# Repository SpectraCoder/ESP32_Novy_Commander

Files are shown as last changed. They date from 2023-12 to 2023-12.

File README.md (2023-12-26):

# ESP32 Novy Commander

The main goal of this project is to control the lights of the Novy Crystal 26050 cooking hood when the Zigbee kitchen lights are turned on or off.
The ESP32 looks at the API of Home Assistant to determine the on or off state of the kitchen lights, and sends a 433mhz signal to the connected 433mhz transmitter.
The ip address of the ESP32 shows a basic status web page with the ability to reboot the device.
 
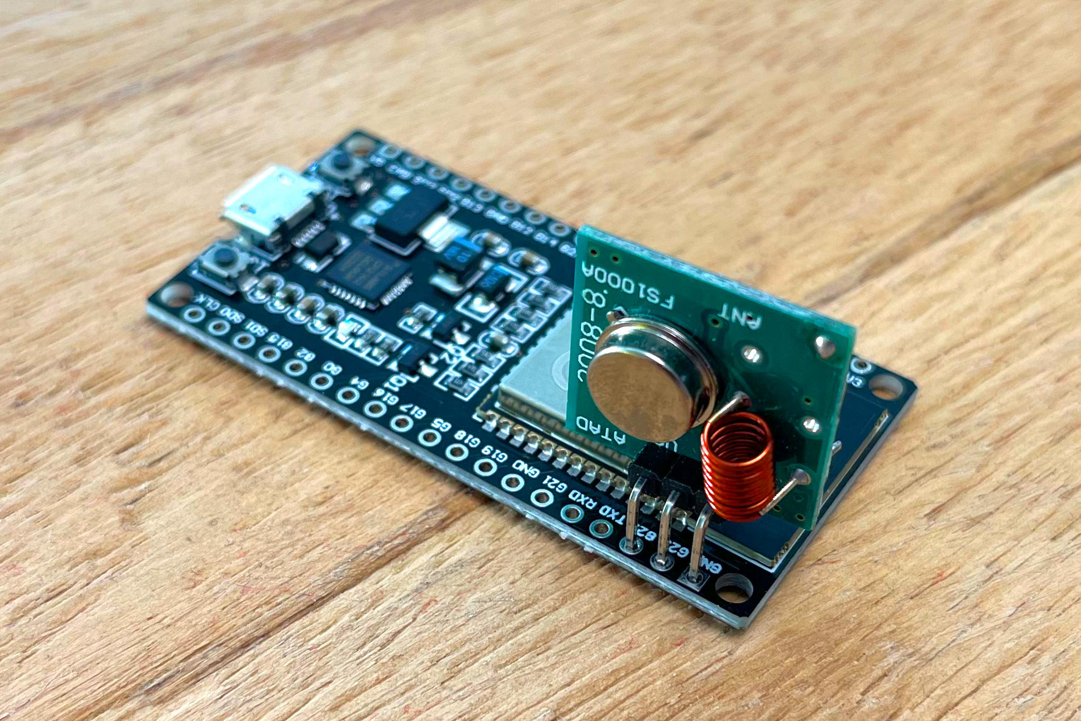
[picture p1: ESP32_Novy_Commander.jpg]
ESP32 with a 433mhz transmitter soldered onto it


For convenience, I soldered the XD-FST FS1000A 433mhz transmitter directly to the ESP32.
By setting pin 22 to HIGH, it powers the transmitter while pin 23 is used to send data.
The pin next to those is ground.

## Usage

To use this in your own setup, make a copy of the [***config.example.h***](https://github.com/SpectraCoder/ESP32_Novy_Commander/blob/main/config.example.h) file. Rename it to ***config.h***.
Change the contents of the file to your own needs.

To be able to access the API of your Home Assistant, you will need to generate a [Long-Lived Access Token](https://www.home-assistant.io/docs/authentication/).
Log in onto your Home Assistant web interface, and click on your profile name. There, on the bottom of the page, you can generate the token. Copy and paste it into the ***config.h*** file.

## Case

I also designed and 3D printed a case for the ESP32 to fit the 433mhz transmitter. You can find the .stl file in [***/Case***](https://github.com/SpectraCoder/ESP32_Novy_Commander/blob/main/Case/).

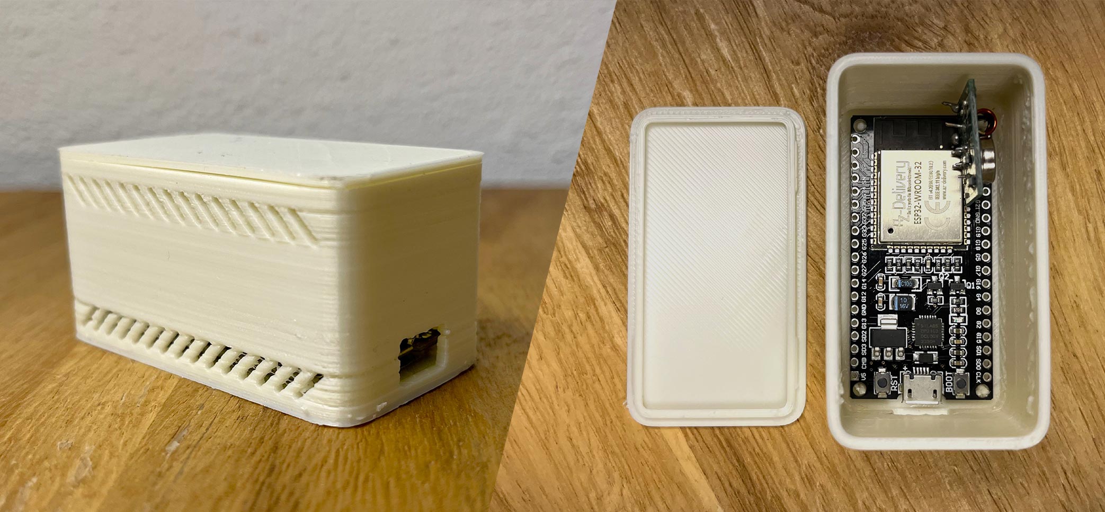
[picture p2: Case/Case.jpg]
ESP32 with a 433mhz transmitter into a 3D printed case


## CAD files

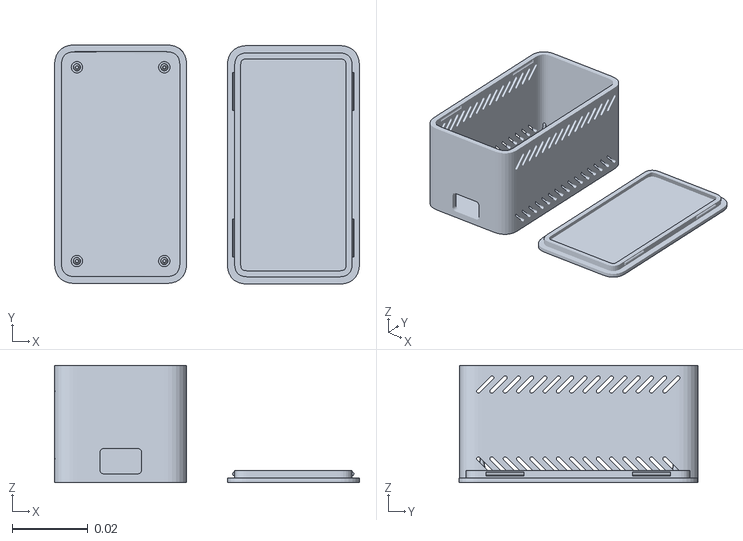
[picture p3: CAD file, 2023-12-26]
Case/ESP32_Novy_Commander_Case_v2.stl
0.0803 x 0.063 x 0.0309

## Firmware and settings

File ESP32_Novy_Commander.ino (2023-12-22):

/// The main goal of this script is to control the lights of the Novy cooking hood when the Zigbee kitchen lights are turned on or off.
/// This script looks at the API of Home Assistant to determine the on or off state of the kitchen lights, and sends a 433mhz signal to the connected 433mhz transmitter.
/// The ip address of the ESP32 shows a basic status web page with the ability to reboot the device.
/// SpectraCoder 01-12-2023

#include <WiFi.h>
#include <WiFiClient.h>
#include <WebServer.h>
#include <ESPmDNS.h>
#include <HTTPClient.h>
#include <ArduinoJson.h>
#include <RCSwitch.h>
#include <ESPmDNS.h>
#include <WiFiUdp.h>
#include <ArduinoOTA.h>

/// IMPORTANT! This file holds all credentials and settings.
/// Make a copy of config.example.h and rename it to config.h to make this work with your own setup.
#include "config.h"
#include "favicon.h"

bool isKitchenLightsOn = false;
int kitchenLightBrightness = 0;
bool isNovyLightOn = false;

WebServer server(80);

RCSwitch transmitter = RCSwitch();

String returnedAPIString = "";

void setup() {
  Serial.begin(115200);
  pinMode(POWER_433MHZ_PIN, OUTPUT);
  digitalWrite(POWER_433MHZ_PIN, HIGH);

  connectWifi();
  startServer();

  transmitter.enableTransmit(TRANSMIT_433MHZ_PIN);
  transmitter.setPulseLength(350);
  transmitter.setProtocol(12);

  ArduinoWifiUpdater();
}

///This function allows for firmware uploads through wifi,
///instead of connecting the ESP32 directly via usb.
void ArduinoWifiUpdater() {
  ArduinoOTA
    .onStart([]() {
      String type;
      if (ArduinoOTA.getCommand() == U_FLASH)
        type = "sketch";
      else  // U_SPIFFS
        type = "filesystem";

      // NOTE: if updating SPIFFS this would be the place to unmount SPIFFS using SPIFFS.end()
      Serial.println("Start updating " + type);
    })
    .onEnd([]() {
      Serial.println("\nEnd");
    })
    .onProgress([](unsigned int progress, unsigned int total) {
      Serial.printf("Progress: %u%%\r", (progress / (total / 100)));
    })
    .onError([](ota_error_t error) {
      Serial.printf("Error[%u]: ", error);
      if (error == OTA_AUTH_ERROR) Serial.println("Auth Failed");
      else if (error == OTA_BEGIN_ERROR) Serial.println("Begin Failed");
      else if (error == OTA_CONNECT_ERROR) Serial.println("Connect Failed");
      else if (error == OTA_RECEIVE_ERROR) Serial.println("Receive Failed");
      else if (error == OTA_END_ERROR) Serial.println("End Failed");
    });

  ArduinoOTA.begin();
}

void startServer() 
{
  server.stop();
  server.on("/", webpage);
  server.on("/reboot", reboot);
  server.on("/favicon.ico", HTTP_GET, getFavicon);
  server.begin();
}

void connectWifi() {
  delay(4000);  //Delay needed before calling the WiFi.begin

  WiFi.mode(WIFI_STA);
  WiFi.disconnect(true);
  WiFi.config(INADDR_NONE, INADDR_NONE, INADDR_NONE, INADDR_NONE);
  WiFi.setHostname(HOSTNAME.c_str());
  WiFi.begin(SSID, PASSWORD, 0, ROUTER_TO_CONNECT_TO);

  while (WiFi.status() != WL_CONNECTED) {
    delay(1000);
    Serial.println("Connecting to WiFi..");
  }

  Serial.println("Connected to the WiFi network " + String(SSID));
  Serial.println(WiFi.localIP());
}

void loop() {
  //Check the current connection status
  if ((WiFi.status() == WL_CONNECTED)) {
    ArduinoOTA.handle();

    returnedAPIString = getHomeAssistantAPIString();

    isKitchenLightsOn = convertJsonToBool(returnedAPIString);
    kitchenLightBrightness = convertJsonToBrightness(returnedAPIString);

    Serial.println(isKitchenLightsOn ? "The kitchen lights are on" : "The kitchen lights are off");

    if (isKitchenLightsOn && !isNovyLightOn) 
    {

      /// The Novy cooking hood lights always start up in full brightness. To dim them down, you need to press and hold the dim button.
      /// It is possible to simulate that button hold by sending the LightOn signal multiple times in a row.
      /// I decided against that, and just leave them off when the other kitchen lights are dimmed below the threshold. (e.g. at night)
      /// Otherwise there would be a flash of light from the cooking hood before it dimmed down to a good level.
      if (kitchenLightBrightness > 200) 
      {
        LightOn();
        isNovyLightOn = true;
        Serial.println("Turned on Novy light");
      }
    }

    if (!isKitchenLightsOn && isNovyLightOn) 
    {
      LightOff();
      isNovyLightOn = false;
      Serial.println("Turned off Novy light");
    }
  }

  if (WiFi.status() != WL_CONNECTED) {
    Serial.println("Lost connection. Reconnecting...");

    connectWifi();
    startServer();
  }

  server.handleClient();

  delay(REFRESH_TIME);
}

String getHomeAssistantAPIString() {
  HTTPClient http;
  String string = "";
  //Url of the Home Assistant API kitchen lights
  http.begin(HOME_ASSISTANT_LIGHT_URL);
  http.addHeader("Authorization", HOME_ASSISTANT_TOKEN);  //Adds the authorization header
  int httpCode = http.GET();                              //Makes the request

  if (httpCode > 0) {
    string = http.getString();

    Serial.print("WiFi signal strength: ");
    Serial.println(WiFi.RSSI());
  } else {
    Serial.println("Error on HTTP request");
  }

  http.end();  //Frees the resources

  return string;
}

/// Checks to which wifi router the ESP32 is connected by comparing the mac addresses of the configured routers in config.h.
/// It returns a friendly name to know which one it is connected to.
String GetFriendlyRouterName() 
{
  /// This compares the first n bytes (where n is the third argument, in this case 6) of
  /// the block of memory pointed by bssid with the first n bytes pointed by bssid_bedroom or bssid_livingroom.
  /// It returns 0 if the two blocks of memory are identical.
  String routerName = "";
  uint8_t* bssid = WiFi.BSSID();

  if (memcmp(bssid, BSSID_BEDROOM, 6) == 0) 
  {
    routerName = "bedroom";
  } 
  else if (memcmp(bssid, BSSID_LIVINGROOM, 6) == 0) 
  {
    routerName = "living room";
  } 
  else 
  {
    routerName = "unknown BSSID";
  }

  return routerName;
}

void getFavicon ()
{
  server.sendHeader("Content-Type", "image/x-icon");
  server.send_P(200, "image/x-icon", (const char*)FAVICON, sizeof(FAVICON));
}

void webpage() {
  int rssi = WiFi.RSSI();
  int signalStrength = map(rssi, -100, -50, 0, 100);
  signalStrength = constrain(signalStrength, 0, 100);

  String routerName = GetFriendlyRouterName();

  String html = R"(
  <html>
    <head>
     <title>)" + String(HOSTNAME)
                + R"(</title>
    <meta http-equiv="refresh" content=")"
                + String(REFRESH_TIME / 1000) + R"(">
    <link rel="icon" type="image/x-icon" href="/favicon.ico">
      <style>
        body {
          background-color: #111111;          
        }
        h1{
          font-family: verdana;
          color: white;
        }
        p {
          font-family: verdana;
          color: white;
        }
        pre{
          color: lightgray;
        }
        .json{
          margin-top: 50px;
          background-color: black;
        }
        .button {
          background-color: blue;
          border: none;
          color: white;
          padding: 15px 32px;
          text-align: center;
          text-decoration: none;
          display: inline-block;
          font-size: 16px;
          margin: 4px 2px;
          cursor: pointer;
        }
      </style>
    </head>
    <body>
      <h1>)" + String(HOSTNAME)
                + R"(</h1>
      <div>
        <p>Connected to )"
                + WiFi.SSID() + R"( ()" + routerName + R"()</p>
        <p>WiFi Signal Strength: )"
                + String(signalStrength) + R"(% ()" + String(rssi) + R"()</p>
        <p>)" + String(isKitchenLightsOn ? "The kitchen lights are on" : "The kitchen lights are off")
                + R"(</p>
        <p>Brightness: )"
                + String(kitchenLightBrightness) + R"(</p>
        <p>Used Heap Size: )"
                + getUsedHeapPercentage() + R"(</p>
        <p>Uptime: )"
                + getUptime() + R"(</p>
        <button class="button" onclick="location.href='/reboot'">Reboot</button>
      </div>
      <div class='json'>
        <pre>)" + beautifyJson(returnedAPIString)
                + R"(</pre>
      </div>
    </body>
  </html>
  )";

  server.send(200, "text/html", html);
}

void reboot() {
  String html = R"(<html>
                  <head>
                  <title>Rebooting...</title>
                    <meta http-equiv='refresh' content='10; url=/'>
                      <style>
                        body {
                          background-color: #111111;          
                        }                      
                        p {
                          font-family: verdana;
                          color: white;
                        }                        
                      </style>
                  </head>
                  <body>
                    <p>Rebooting...</p>
                  </body>
                </html>)";

  server.send(200, "text/html", html);
  delay(1000);
  ESP.restart();
}

String getUptime() 
{
  uint64_t timeSinceBoot = esp_timer_get_time();
  uint64_t seconds = timeSinceBoot / 1000000;
  uint64_t minutes = seconds / 60;
  uint64_t hours = minutes / 60;
  uint64_t days = hours / 24;
  seconds = seconds % 60;
  minutes = minutes % 60;
  hours = hours % 24;
  String uptime = String(days) + " days, " + String(hours) + " hours, " + String(minutes) + " minutes, " + String(seconds) + " seconds";

  return uptime;
}


/// Function to calculate the percentage of used memory
String getUsedHeapPercentage() 
{
  // Get the free heap size
  uint32_t freeHeap = esp_get_free_heap_size();

  // Define the total heap size
  uint32_t totalHeap = 320 * 1024;  // 320KB

  // Calculate the used heap size
  uint32_t usedHeap = (freeHeap > totalHeap) ? 0 : (totalHeap - freeHeap);

  // Calculate the percentage of used heap
  float usedHeapPercentage = ((float)usedHeap / totalHeap) * 100;

  // Return the used heap size and percentage as a string
  return String(usedHeap) + " bytes (" + String(usedHeapPercentage) + "%)";
}

String beautifyJson(String jsonString) 
{
  //Create an empty Json object
  StaticJsonDocument<1500> jsonDoc;

  //Load the received data into a JSON object
  DeserializationError error = deserializeJson(jsonDoc, jsonString);

  if (!error) 
  {
    String prettyJson;
    serializeJsonPretty(jsonDoc, prettyJson);
    return prettyJson;
  } 
  else 
  {
    return String("ERROR: Json could not be read");
  }
}

/// Converts the "brightness" property inside the json (returned by Home Assistant) to an int.
/// Returns an int from 0 to 255.
int convertJsonToBrightness(String jsonString) 
{
  //Create an empty Json object
  StaticJsonDocument<1500> jsonDoc;

  //Load the received data into a JSON object
  DeserializationError error = deserializeJson(jsonDoc, jsonString);

  // Test if parsing succeeds.
  if (error) 
  {
    Serial.print(F("deserializeJson() failed: "));
    Serial.println(error.f_str());
    return 0;
  }

  JsonObject root = jsonDoc.as<JsonObject>();
  JsonObject attributes = root["attributes"].as<JsonObject>();
  int brightness = attributes["brightness"];

  return brightness;
}


///Converts the "state" property inside the json (returned by Home Assistant) to a bool.
///Returns true if the state is "on", false if it is "off".
bool convertJsonToBool(String jsonString) 
{
  //Create an empty Json object
  StaticJsonDocument<1500> jsonDoc;

  //Load the received data into a JSON object
  DeserializationError error = deserializeJson(jsonDoc, jsonString);

  // Test if parsing succeeds.
  if (error) 
  {
    Serial.print(F("deserializeJson() failed: "));
    Serial.println(error.f_str());
    return false;
  }

  // Get the state value inside the JSON object
  const char* state = jsonDoc["state"];

  // Convert to boolean
  bool isOn = strcmp(state, "on") == 0;

  return isOn;
}


void PressLight(int channelIndex) 
{
  Serial.print("Pressing light on channel ");
  Serial.println(channelIndex);
  Serial.print((NOVY_DEVICE_CODE[channelIndex] + NOVY_PREFIX + NOVY_COMMAND_LIGHT).c_str());
  Serial.println();
  //010101010111010001
  transmitter.send((NOVY_DEVICE_CODE[channelIndex] + NOVY_PREFIX + NOVY_COMMAND_LIGHT).c_str());
}

void LightOn() 
{
  PressLight(0);
}

void LightOff()
{
  PressLight(0);
}

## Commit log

2023-12-17 Added a picture of the ESP32
2023-12-26 Added 3D model of the case
    [ESP32_Novy_Commander_Case_v2.stl]
2023-12-26 Added a picture of the case to the readme
